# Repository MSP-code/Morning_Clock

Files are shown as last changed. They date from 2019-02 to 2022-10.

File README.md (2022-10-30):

# Morning_Clock
An alarm clock with dawn effect based on AVR ATmega8 MCU with RTC

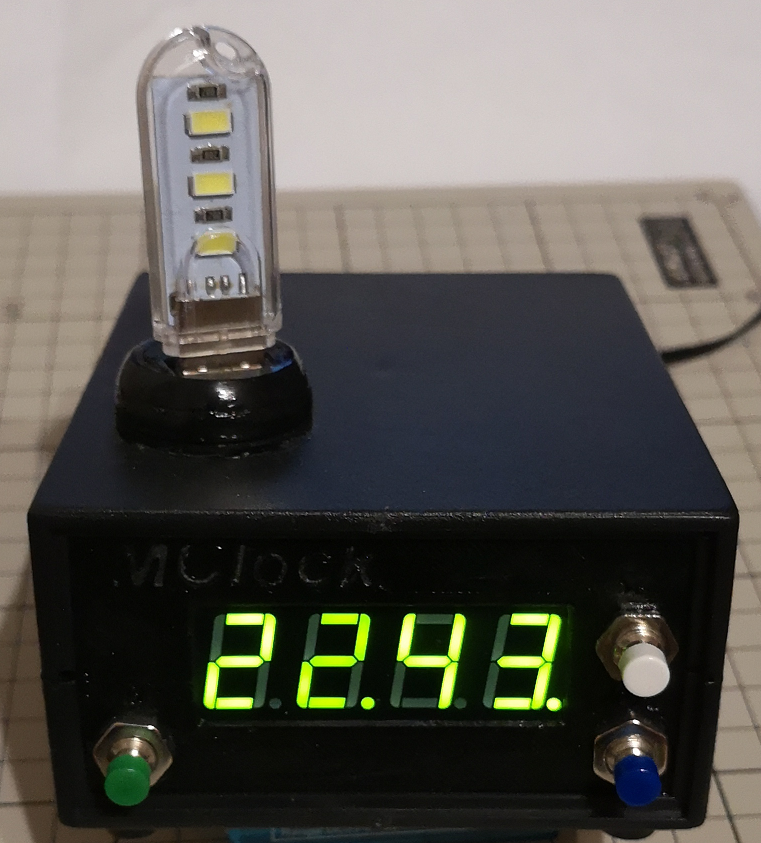
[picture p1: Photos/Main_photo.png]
Morning Clock

## Description
This a simle alarm clock with dawn effect based on AVR ATmega8.
## Features
* It uses RTC on its asyncronic timer only external quartz 32768Hz is necessary.
* Gamma corrected (logarithmicall) LED PWM control.
* Supports any light sourse via USB output up to 1A (depends on transistor). **Warning** there is no current limitation, if R3 is not installed.
* Alarm can be turned on/off for each day of week.
* Selectable dawn length.
* No annoying beeper ;)
* All constant settings are stored in EEPROM
* In case of power failure, clock will continue to operate from battery (3xAAA)
## Menu Modes/Manual
Modes are given in switching order, and are changed by pressing **Set** button.
* Clock - **default mode** - shows current time. Second dot (HH.MM) is blinking in all modes with frequency 0.5Hz indicating that clock is working. Buttons operations:
  * **H button** - press to increase value of hours.
  * **M/D button** - press to increase value of minutes.
  * **H + M/D button for small time** - press to turn on or off alarm clock globally. On - 4th dot is lit (HHMM.), off - 4th dot is not lit.
* Alarm Сlock- shows alarm time. This mode is indicated by first dot (H.HMM). Alarm Clock time is the dawn end time. For example, if dawn perion is half an hour, and alarm is set to 7:30, then dawn will start at 7:00. Buttons operations:
  * **H button** - press to increase value of alarm hours.
  * **M/D button** - press to increase value of alarm minutes.
* DAY_SET - **ds 5** - setting day of the week 1-7.
  * **M/D button** - press to set day.
* Al_Mon - **dA 1** -  turns on/off alarm for 1st day of the week.
  * **M/D button** - press to turn on alarm (4th dot is lit (HHMM.)  or off ( 4th dot is not lit.).
*	Al_Tue -**dA 2** - turns on/off alarm for 2st day of the week. Works similar to Al_Mon.
*	Al_Wed -**dA 3**.
*	Al_Thu -**dA 4**.
*	Al_Fri -**dA 5**.
*	Al_Sut -**dA 6**.
*	Al_Sun -**dA 7**
* Bright -**br 1** - set display brightness.
  * **M/D button** - press to set brightness - 2 bright, 1- dim.
* Indication - **In 0** - indication period. 0 - clock diplays data only 60 sec, then only second and 4th dot is lit. 1- constant light.
  * **M/D button** - press to set Indication - 1 constant, 0- 60 second.
  * **H button or M/D button** - shot press to turn on display.
* Dawn Period -**dP25** - dawn period - from 15 to 30 minutes with step 5 minutes.
  * **M/D button** - press to set dawn period
### Global buttons operations
* When alarm is working (light is turned on) is can be switched off by short press of **H button or M/D button**.
* Press **H button or M/D button** to turn on display when indication mode 0 is selected.
## TBD (probably will be added):
* Add speaker and make beeps when alarm time is on (**!**  Is not supported by current pcb);
* Add time correction per day.

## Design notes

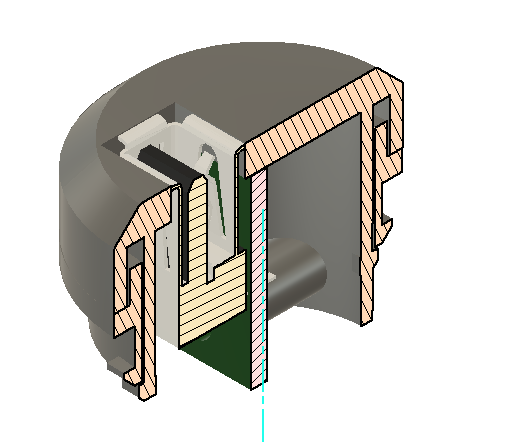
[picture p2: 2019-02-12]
Photos/USB_Holder_Section.PNG

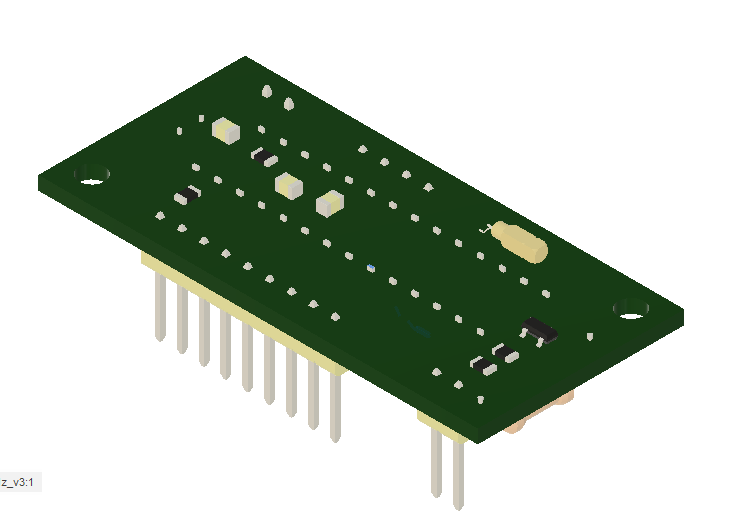
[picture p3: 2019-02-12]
Photos/main_pcb_back.PNG

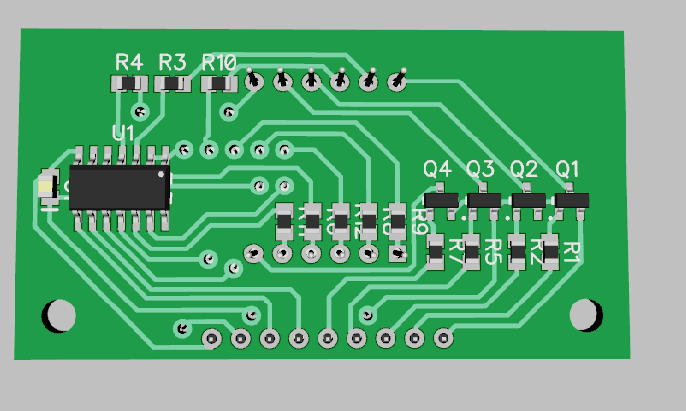
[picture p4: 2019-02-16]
Photos/4digit_back.PNG

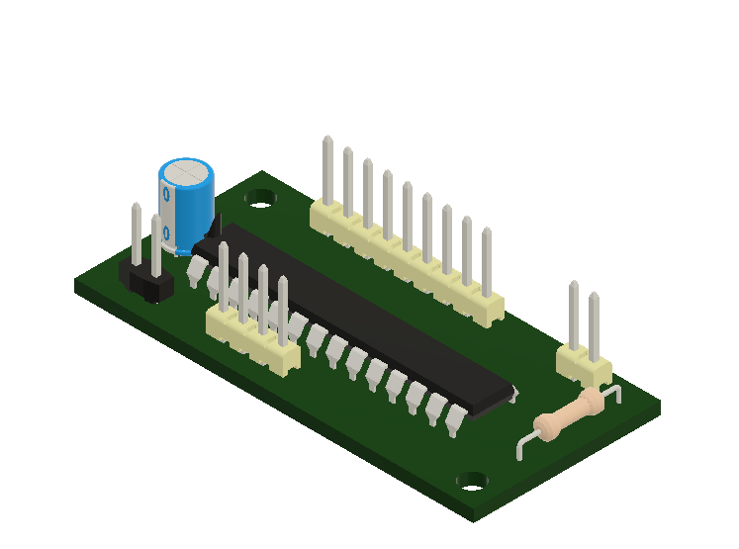
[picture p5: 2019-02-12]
Photos/main_pcb_front.PNG

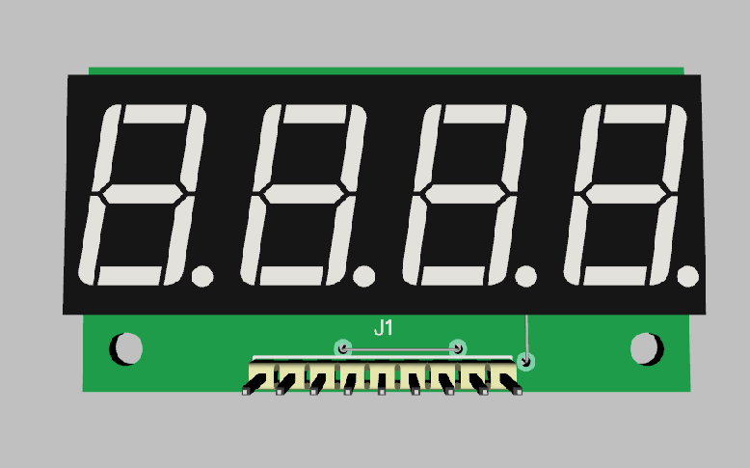
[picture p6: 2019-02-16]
Photos/4digit_front.PNG

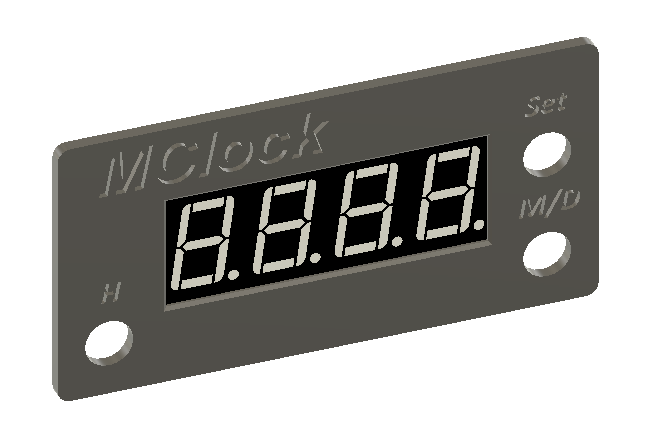
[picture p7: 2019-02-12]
Photos/Front_plate.PNG

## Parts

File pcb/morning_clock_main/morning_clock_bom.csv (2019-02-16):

# | RefDes | Value | Name
1 | C1 | 100n | CAP_0805
2 | C2 | 100u | CAP100RP
3 | C3 | 100n | CAP_0805
4 | C4 | 100n | CAP_0805
5 | J1 | Vcc_in | PLS-3 (PLS with step 2.54)
6 | J2 | Disp | 644456-9 (PLS with step 2.54)
7 | J3 | Buttons | 644456-4 (PLS with step 2.54)
8 | J4 | LED | 644456-2 (PLS with step 2.54)
9 | Q1 |  | IRLML2402
10 | R1 | 10K | RES_0805
11 | R2 | 10 | RES_0805
12 | R3 |  | RES500
13 | R4 | 10K | RES_0805
14 | R5 |  | RES_0805
15 | U1 |  | ATmega8-16PI
16 | U2 |  | MS3V-T1R_32.768KHZ_+-20PPM_12.

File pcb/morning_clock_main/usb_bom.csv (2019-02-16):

# | RefDes | Value | Name
1 | J1 |  | 292303-2 USB type A on board
2 | XT1 |  | PLS-2 (PLS with step 2.54)

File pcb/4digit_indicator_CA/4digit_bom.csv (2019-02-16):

# | RefDes | Value | Name
1 | C1 | 100n | CAP_0805
2 | J1 |  | 644456-9 (PLS with step 2.54, if necessary)
3 | Q1 |  | BC857C
4 | Q2 |  | BC857C
5 | Q3 |  | BC857C
6 | Q4 |  | BC857C
7 | R1 | 1K | RES_0805
8 | R2 | 1K | RES_0805
9 | R3 | 100 | RES_0805
10 | R4 | 100 | RES_0805
11 | R5 | 1K | RES_0805
12 | R6 | 100 | RES_0805
13 | R7 | 1K | RES_0805
14 | R8 | 100 | RES_0805
15 | R9 | 100 | RES_0805
16 | R10 | 100 | RES_0805
17 | R11 | 100 | RES_0805
18 | R12 | 100 | RES_0805
19 | U1 |  | SN74HC164D
20 | U2 |  | ULF-5461BG 4 digit display

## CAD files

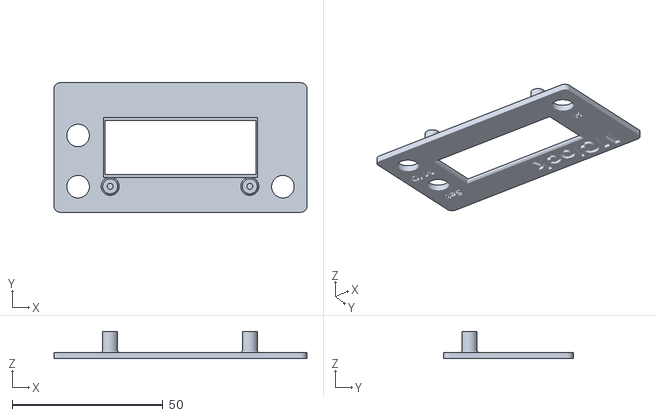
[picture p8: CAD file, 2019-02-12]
3dmodels/Front_plate.stl
84.0 x 43.0 x 9.10

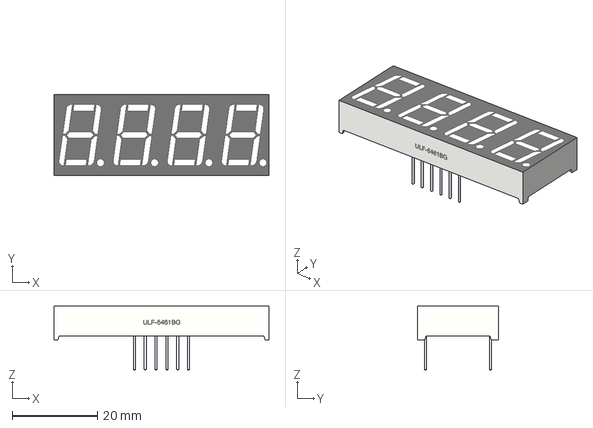
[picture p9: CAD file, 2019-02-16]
pcb/4digit_indicator_CA/Indicator ULF 5461 BG (Green) v4.step
50.4 x 19.0 x 15.0 mm

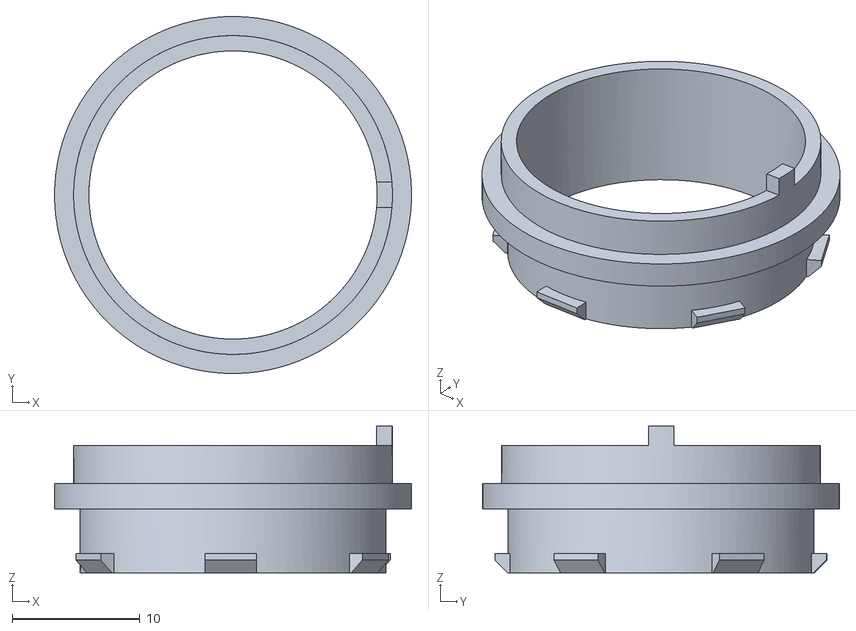
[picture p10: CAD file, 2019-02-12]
3dmodels/ring.stl
28.0 x 28.0 x 11.5

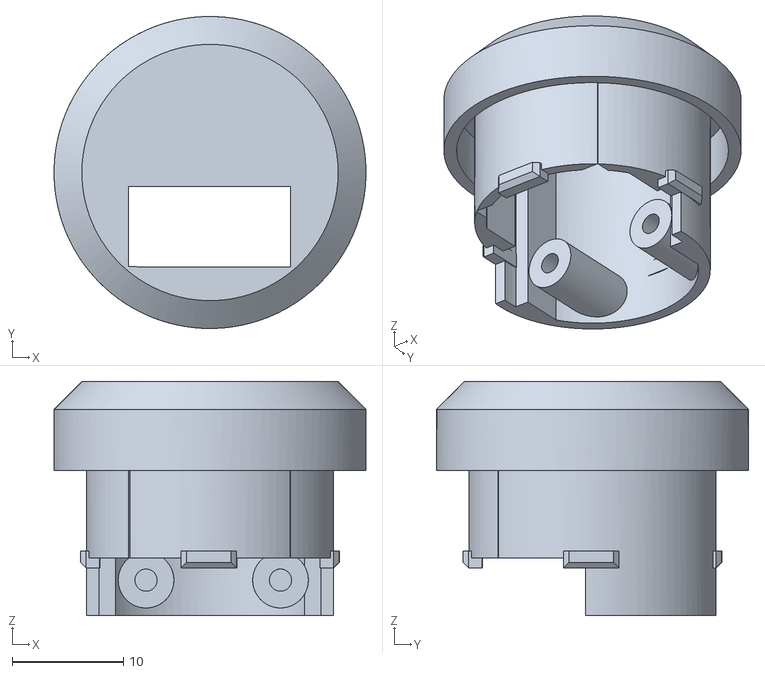
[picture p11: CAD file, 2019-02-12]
3dmodels/USB-holder.stl
28.0 x 28.0 x 21.0

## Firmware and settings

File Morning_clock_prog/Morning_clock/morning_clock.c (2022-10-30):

// SignallerK 2019 -v 1.4.0
//added back_up battery control
//corrected small bugs and refactored code
#include <avr/io.h>
#include <avr/interrupt.h>
#include <avr/sleep.h>
#include <util/delay.h>
#include "bits_macros.h"
#include <avr/eeprom.h>
#include <avr/pgmspace.h>
#include "Led_PWM_256.h"
#include "morning_clock.h"
#include <util/atomic.h>

//time structure
typedef struct{
	unsigned char second;
	unsigned char minute;
	unsigned char hour;
	unsigned char week_day;
	//    unsigned char date;
	//    unsigned char month;
	//    unsigned int year;
} time;

time t;



//working variables
uint8_t digits[4];
volatile uint8_t current_digit;

//set alarm to on mode
unsigned char dawn_on = 1;
// alarm variables
volatile uint8_t dawn_counter =0;
uint8_t dawn_step; //sec
uint8_t PWM_SEC_Counter=0;

//set indication and brightness
uint8_t indication_counter=indication_period;//sec
volatile uint8_t brightness_counter=BRIGHTNESS_INIT;
uint8_t update_display_flag=1;
//buttons variables
uint8_t m_pressed = 0, h_pressed=0; //button is pressed
uint16_t button_delay=0;           //button delay counter ()


void BIN2BCD(uint8_t *buffer, unsigned int n)
{
	buffer[0]=0;
	while(n>=10) {buffer[0]++;n-=10;}
	buffer[1]=n;
}

void SPI_MasterInit(void)
{
	
	/* Enable SPI, Master, set clock rate fck/16 */
	SPCR = (1<<SPE)|(1<<MSTR)|(1<<SPR0);
}
void SPI_MasterTransmit(char cData)
{
	/* Start transmission */
	SPDR = cData;
	/* Wait for transmission complete */
	while(!(SPSR & (1<<SPIF)))
	;
}




int main(void)
{
	// wait for quartz stabilization
	#ifdef NDEBUG
	_delay_ms(500);
	#endif

	// Input/Output Ports initialization
	// Port B initialization

	// Function: Bit7=In Bit6=In Bit5=Out Bit4=In Bit3=Out Bit2=OUT Bit1=Out Bit0=In
	DDRB=(0<<DDB7) | (0<<DDB6) | (1<<DDB5) | (0<<DDB4) | (1<<DDB3) | (1<<DDB2) | (1<<DDB1) | (0<<DDB0);

	// State: Bit7=T Bit6=T Bit5=0 Bit4=T Bit3=0 Bit2=1 Bit1=0 Bit0=T
	PORTB=(0<<PORTB7) | (0<<PORTB6) | (0<<PORTB5) | (0<<PORTB4) | (0<<PORTB3) | (1<<PORTB2) | (0<<PORTB1) | (0<<PORTB0);

	// Ports initialization
	DRV_PORT=0x00;
	DRV_DDR=DRV_CONN;

	BUT_PORT|= 0b11100;         //buttons set
	BUT_DDR=0;
	//battery port
	BAT_PORT&=~(1<<BAT_CONN);
	BAT_DDR &=~(1<<BAT_CONN);


	SPI_MasterInit();
	
	// External Interrupt(s) initialization
	// INT0: On
	// INT0 Mode: Any change
	// INT1: On
	// INT1 Mode: Any change
	GICR|=(1<<INT1) | (1<<INT0);
	MCUCR=(0<<ISC11) | (1<<ISC10) | (0<<ISC01) | (1<<ISC00);
	GIFR=(1<<INTF1) | (1<<INTF0);

	// Timer/Counter 0 initialization - indication counter
	// Clock source: System Clock
	// Clock value: 125,000 kHz
	// Timer Period: 2,048 ms
	TCCR0=(0<<CS02) | (1<<CS01) | (1<<CS00);
	TCNT0=0x00;

	// Timer/Counter 1 initialization -pwm counter
	// Clock source: System Clock
	// Clock value: 500,000 kHz
	// Mode: Fast PWM top=0x00FF
	// OC1A output: Non-Inverted PWM
	// Timer Period: 0,512 ms

	TCCR1A=(1<<COM1A1) | (0<<COM1A0) | (0<<COM1B1) | (0<<COM1B0) | (0<<WGM11) | (1<<WGM10);//0x81
	TCCR1B=(0<<ICNC1) | (0<<ICES1) | (0<<WGM13) | (1<<WGM12) | (0<<CS12) | (1<<CS11) | (0<<CS10);//0x0A
	TCNT1=0;// turn off timer
	OCR1A=0;
	TCCR1A=0x00; //disconnect timer;

	//###########################################	'
	//Prepare to start
	// turn off timer 2 interrupts
	
	TIMSK &= ~((1<<TOIE2) | (1<<OCIE2));

	// Timer 2 to async mode routine (clock quartz)
	ASSR |= (1<<AS2);

	TCNT2 = 0x00;
	TCCR2 = 0x05; //timer prescaler ratio 128.
	OCR2  = 0x00;

	// waiting for timer readiness.
	while (ASSR & ((1<<TCN2UB) | (1<<OCR2UB) | (1<<TCR2UB)));

	// Timer 2 interrupts on.
	TIMSK |= (1<<TOIE2);
	// Timer 0 interrupts on
	TIMSK |= (1<<TOIE0);
	
	// turn on global params
	menu = Clock;
	t.week_day=1;
	//calculate dawn step
	dawn_step = ((((uint16_t)eeprom_read_byte(&dawn_period))*60)+PWM_TOP/2)/PWM_TOP;
	
	//small trick for simulation, if eeprom wasn't downloaded
	#ifdef DEBUG
	eeprom_write_byte(&brightness,1);
	
	#endif
	//sleep mode
	set_sleep_mode(SLEEP_MODE_PWR_SAVE);
	// global interrupts on
	sei();

	while(1)
	{
		//Prepare indication data
		ATOMIC_BLOCK(ATOMIC_RESTORESTATE)
		{
			if (update_display_flag)
			{
				switch (menu) {
					case Clock:
					BIN2BCD(digits, t.hour);
					BIN2BCD(digits+2, t.minute);
					break;
					
					case Alarm:
					BIN2BCD(digits, eeprom_read_byte(&dawn_hour));
					BIN2BCD(digits+2, eeprom_read_byte(&dawn_minute));
					break;
					case  DAY_SET:
					digits[0]=seg_to_d;//d
					digits[1]=seg_to_S;//S
					BIN2BCD(digits+2,t.week_day );
					digits[2]=seg_to_void;//void
					break;
					case Al_Mon:
					case Al_Tue:
					case Al_Wed:
					case Al_Thu:
					case Al_Fri:
					case Al_Sut:
					case Al_Sun:
					digits[0]=seg_to_d;//d
					digits[1]=seg_to_A;//A
					BIN2BCD(digits+2,menu-DAY_SET);
					digits[2]=seg_to_void;//void
					break;
					case Bright:
					digits[0]=seg_to_b;//b
					digits[1]=seg_to_r;//r
					BIN2BCD(digits+2,eeprom_read_byte(&brightness));
					digits[2]=seg_to_void;//void
					break;
					case Indication:
					digits[0]=seg_to_I;//I
					digits[1]=seg_to_n;//n
					BIN2BCD(digits+2,eeprom_read_byte(&indication_flag));
					digits[2]=seg_to_void;//void
					break;
					case Dawn_Time:
					digits[0]=seg_to_d;//d
					digits[1]=seg_to_P;//P
					BIN2BCD(digits+2,eeprom_read_byte(&dawn_period));
					break;
					
					default:
					menu=Clock;
				}
				update_display_flag=0;
			}
		}
		
		while(BitIsClear(BAT_PIN, BAT_CONN))
		{
			
			DRV_PORT|=0x0F;
			// Timer 0 interrupts off
			TIMSK &= ~(1<<TOIE0);
			
			//if light is on - turnoff
			if (dawn_counter)
			{
				TCNT1=0;// turn off timer
				OCR1A=0;
				TCCR1A=0x00; //disconnect timer;
				dawn_counter=0;//clear counter
				PWM_SEC_Counter=0;//clear counter
			}
			/*sleep_enable();
			sleep_cpu();
			sleep_disable();*/
			sleep_mode();
			if (BitIsSet(BAT_PIN, BAT_CONN))
			{
				// Timer 0 interrupts on
				TIMSK |= (1<<TOIE0);
			}
		}
		
	}

	return 0;
}

//###########################################
//Clock interrupt every 1 sec
ISR(TIMER2_OVF_vect) //overflow interrupt vector
{
	update_display_flag=1;
	//indication time check
	if(indication_counter)
	{
		indication_counter--;
		if (!indication_counter)
		{
			menu=Clock;
			//if constant indication is on,then reset counter to default value
			if(eeprom_read_byte(&indication_flag))
			indication_counter=indication_period;
		}
	}

	//PWM alarm routine
	
	if(dawn_counter)
	{
		if(++PWM_SEC_Counter==dawn_step)
		{
			PWM_SEC_Counter=0;
			
			dawn_counter--;
			OCR1A=pgm_read_byte(&cie[(uint8_t)(~dawn_counter)]);
			
			if (!dawn_counter)
			{
				TCNT1=0;// turn off timer
				OCR1A=0;
				TCCR1A=0x00; //disconnect timer;
			}
		}
	}
	
	
	//This code from avr appnoute count time
	
	if (++t.second==60)     //keep track of hours minutes
	{
		t.second=0;
		
		//Clear menu and button
		button_delay=0;
		
		
		if (++t.minute==60)
		{
			t.minute=0;

			if (++t.hour==24)
			{
				t.hour=0;
				if (++t.week_day==8)
				{
					t.week_day=1;
				}
			}
		}
		
		// dawn checking function
		if (dawn_on&&eeprom_read_byte(&week_day_al[t.week_day-1]))
		{
			
			uint8_t temp_dw_hour=eeprom_read_byte(&dawn_hour);
			uint8_t temp_dw_minute=eeprom_read_byte(&dawn_minute);
			//calculate actual start as alarm - dawn_period
			if (temp_dw_minute>=eeprom_read_byte(&dawn_period))
			{
				temp_dw_minute=temp_dw_minute-eeprom_read_byte(&dawn_period);
			}
			else
			{
				if (temp_dw_hour==00)
				{
					temp_dw_hour=24;
				}
				temp_dw_hour--;
				temp_dw_minute=60-eeprom_read_byte(&dawn_period)+temp_dw_minute;
			}
			//check if time to start
			if (temp_dw_hour==t.hour)
			{
				if (temp_dw_minute==t.minute)
				{
					dawn_counter=PWM_TOP;
					OCR1A=0;//
					TCNT1=0;
					TCCR1A=0x81; //turn on timer
				}
			}
		}
	}
}
//##############################
//Buttons interrupt

ISR(INT0_vect) //hour button
{
	h_pressed=(BitIsClear(PIND, 2));
	button_delay=0;
	
}

ISR(INT1_vect) //minute button
{
	m_pressed=(BitIsClear(PIND, 3));
	button_delay=0;
}

//##############################
//Main indication routine

ISR(TIMER0_OVF_vect)
{
	DRV_PORT|=0x0F;     //turn off indicator
	
	volatile uint8_t temp=0x00;
	
	/*Prepare dots to on			*/
	if (current_digit==1)   //if dots time
	{
		if (BitIsSet(t.second,0)) //dot every second
		{
			temp=CLEAR_DOT;
		}
		else
		{
			temp=SET_DOT;
		}
	}
	if (current_digit==3)   //if dawn on
	{
		if ((dawn_on==1&& menu==Clock)||((menu>=Al_Mon && menu<=Al_Sun) && eeprom_read_byte(&week_day_al[menu-Al_Mon]))) //alarm indication on
		{
			temp=SET_DOT;//set dot indicator for alarm
		}
		else
		{
			temp=CLEAR_DOT;//clear dot indicator for alarm
		}
	}
	// if indication is on prepare digit value
	if(indication_counter)
	{
		if (current_digit==0)   //if dots time
		{
			if (menu==Alarm) //
			{
				temp=SET_DOT;
			}
			else
			{
				temp=CLEAR_DOT;
			}
		}
		
		temp|=segment[digits[current_digit]];
	}
	brightness_counter -= eeprom_read_byte(&brightness);// check the brightness
	// turn on digit, if brightness 0
	if(!brightness_counter)
	{
		brightness_counter=2;
		SPI_MasterTransmit(~temp); //send digit via spi
		
		ClearBit(DRV_PORT, 3-current_digit);    //turn on current digit
		
		
		if (++current_digit==4)         //if all digits passed
		{
			current_digit=0;
		}
	}
	
	//Interrupt Button debounce
	if (button_delay==BUTTON_DEBOUNCING&&(h_pressed||m_pressed))
	
	{
		indication_counter=indication_period; //update counter
		update_display_flag=1;
		if (dawn_counter)  //if alarm is on, turn off it
		{
			dawn_counter=0;
			TCNT1=0;
			OCR1A=0;
			TCCR1A=0x00;; //disconnect timer
		}
		
	}
	//Button check main cycle
	if (++button_delay==BUTTON_DELAY_CONST) // around 0.4 sec for fixed value
	{
		button_delay=0;
		update_display_flag=1;
		if (menu_pressed&&indication_counter)// menu pressed
		{
			if(++menu== MENU_END)
			{
				menu=0;
				indication_counter=indication_period;
			}
		}
		
		if (h_pressed&&menu_unpressed&&!(m_pressed))  //hour button pressed
		{
			if (menu==Clock)
			{
				if (++t.hour==24)// corrected hours
				{
					t.hour=0;
				}
			}
			else if (menu==Alarm)
			{
				eeprom_write_byte(&dawn_hour, eeprom_read_byte(&dawn_hour)+1);
				
				if (eeprom_read_byte(&dawn_hour)==24)//correct alarm hour
				{
					eeprom_write_byte(&dawn_hour,0);
				}
			}
		}
		if (m_pressed&&menu_unpressed&&!(h_pressed)) //if minute button pressed
		{
			//updates menu item's value
			switch (menu)
			{
				case Clock: //correct minutes
				if (++t.minute==60)
				{
					t.minute=0;
				}
				break;
				case Alarm: //correct alarm minute
				eeprom_write_byte(&dawn_minute, eeprom_read_byte(&dawn_minute)+1);
				if (eeprom_read_byte(&dawn_minute)==60)
				{
					eeprom_write_byte(&dawn_minute,0);
				}
				break;
				//set day
				case DAY_SET:
				if (++t.week_day==8)
				{
					t.week_day=1;
				}
				break;
				//set if day alarm is on
				case Al_Mon:
				case Al_Tue:
				case Al_Wed:
				case Al_Thu:
				case Al_Fri:
				case Al_Sut:
				case Al_Sun:
				if (eeprom_read_byte(&week_day_al[menu-Al_Mon]))//set day alarms
				{
					eeprom_write_byte(&week_day_al[menu-Al_Mon],0);
				}
				else
				{
					eeprom_write_byte(&week_day_al[menu-Al_Mon],1);
				}
				break;
				//correct brightness
				case Bright:
				
				ATOMIC_BLOCK(ATOMIC_RESTORESTATE)
				{
					if (eeprom_read_byte(&brightness)+1==3)
					{
						eeprom_write_byte(&brightness,1);
					}
					else
					eeprom_write_byte(&brightness, eeprom_read_byte(&brightness)+1);
					
					brightness_counter=2;
				}
				break;
				//set indication 1- constant, 0- 60 sec
				case Indication:
				eeprom_write_byte(&indication_flag, eeprom_read_byte(&indication_flag)+1);
				if (eeprom_read_byte(&indication_flag)==2)//set indication time
				{
					eeprom_write_byte(&indication_flag,0);
					
				}
				break;
				//set dawn period
				case Dawn_Time:
				eeprom_write_byte(&dawn_period, eeprom_read_byte(&dawn_period)+5);
				if (eeprom_read_byte(&dawn_period)>30)//correct brightness
				{
					eeprom_write_byte(&dawn_period, 15);
					
				}
				dawn_step = ((((uint16_t)eeprom_read_byte(&dawn_period))*60)+PWM_TOP/2)/PWM_TOP;
				break;
				default:
				break;
			}
			
		}
		
		
		if (h_pressed&&m_pressed&&menu_unpressed) //alarm turn off/on (2 buttons)
		{
			if(menu==Clock||menu==Alarm)
			{
				if(dawn_on)
				{
					dawn_on=0;
				}
				else
				{
					dawn_on=1;
				}
			}
			
		}
	}
	
}

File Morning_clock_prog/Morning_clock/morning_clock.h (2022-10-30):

//############################################
//This file stores main parameters and variables 
//#############################################
#ifndef MORNING_CLOCK_H
#define MORNING_CLOCK_h

#include <avr/io.h>
#include "bits_macros.h"

FUSES =
{
	.low = 0xA4,		//Select cpu clk: Internal calibrated RC-oscillator @ 8MHz
	.high = 0xC1,		
	//.extended = 0xE3,	//Default settings
};

//DEFINES
//Ports defines
//Port C indication port
#define DRV_PORT PORTC
#define DRV_DDR DDRC
#define DRV_CONN 0b00001111
//Port D buttons port
#define BUT_PORT PORTD
#define BUT_DDR DDRD
//Port C battery port
#define BAT_PORT PORTC
#define BAT_DDR DDRC
#define BAT_PIN PINC
#define BAT_CONN 5

//Buttons macro and defines

#define menu_pressed BitIsClear(PIND, 4)
#define menu_unpressed BitIsSet(PIND, 4)
#define BUTTON_DELAY_CONST 300 //constant, time between value change (~0.5 sec)
#define BUTTON_DEBOUNCING 3 // debounce const ~10ms

//Basic parameters defines
#define BRIGHTNESS_INIT 1 //start value of brightness (2 max, 1 dim)
#define indication_period 60//sec  if indication flag 1, other cinst
//Other
#define	PWM_TOP 0xFF	//PWM_TOP don't change
#define CLEAR_DOT 0b00000000
#define SET_DOT 0b10000000

// EEPROM Variables
unsigned char EEMEM dawn_hour =6; //alarm hour
unsigned char EEMEM dawn_minute =50;//alarm minute
unsigned char EEMEM brightness = BRIGHTNESS_INIT; 
unsigned char EEMEM indication_flag = 1;// 1 is constant indication, 0 -one 1 minute
unsigned char EEMEM dawn_period = 25; //dawn period from 15 to 30 step 5
unsigned char EEMEM week_day_al[7]={1,1,1,1,1,0,0}; //week days alarm set

#define DRV_PORT PORTC
#define DRV_DDR DDRC
#define DRV_CONN 0b00001111




// 7 segment translation array
enum seg_nick_name {
	seg_to_A=10, 
	seg_to_d=11,
	seg_to_S=12,
	seg_to_b=13,
	seg_to_r=14,
	seg_to_I=15,
	seg_to_n=16,
	seg_to_P=17,
	seg_to_void=18
	};
uint8_t segment[] =
//pgfedcba+some symbols
{
	0b00111111,     //0
	0b00000110,     //1
	0b01011011,     //2
	0b01001111,     //3
	0b01100110,     //4
	0b01101101,     //5
	0b01111101,     //6
	0b00000111,     //7
	0b01111111,     //8
	0b01101111,     //9
	0b01110111,		//A
	0b01011110,		//d
	0b01101101,		//S
	0b01111100,		//b
	0b01010000,		//r
	0b00110000,		//I
	0b01010100,		//n
	0b01110011,		//P
	0b00000000		//void _
};

// menu types enum
enum menu_item
{
	Clock,
	Alarm,
	DAY_SET,
	Al_Mon,
	Al_Tue,
	Al_Wed,
	Al_Thu,
	Al_Fri,
	Al_Sut,
	Al_Sun,
	Bright,
	Indication,
	Dawn_Time,
	//TBD correction
	MENU_END

} menu;

#endif

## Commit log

2019-02-12 added pcb and Photos
    [Front_plate.stl, Indicator ULF 5461 BG (Green) v4.step, USB-holder.stl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]
2019-02-16 added bom
    [4digit_bom.csv, morning_clock_bom.csv, usb_bom.csv]
2019-02-16 corrected code for brightness bug
    [morning_clock.c]
2019-02-16 Update README.md
    corrected current limitation desription
2019-02-16 added new photos, small corrections in 3d models folder
    [Indicator ULF 5461 BG (Green) v4.step]
2019-11-13 Corrected issue with brightness setting (in morning clock.c)
    [morning_clock.c]
2022-10-30 Morning Clock 1.4.0
    Added battery backup logic
    Added Power Save Sleep
    Refactored code
